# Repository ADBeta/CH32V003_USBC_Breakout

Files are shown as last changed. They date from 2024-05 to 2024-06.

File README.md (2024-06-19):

# CH32V003 USB C Breakout

## Project Description
A Breakout Board for the QFN Variant of the CH32V003, with pins broken out for
I2C, SPI, UART, USB, and with a USB-C Connector, and an NRST Button.  

This Board has been designed with generic and minimal parts, to make the
production and assembly of these boards easy and cheap for novices, looking to
get into the hobby and/or use the `CH32V003` Chips

NOTE: If using the USB Pins for other purposes, please keep in mind that USB_DM
and USB_PU are connected togehter with a 1.5K resistor. Remove this if needed

## Gallery
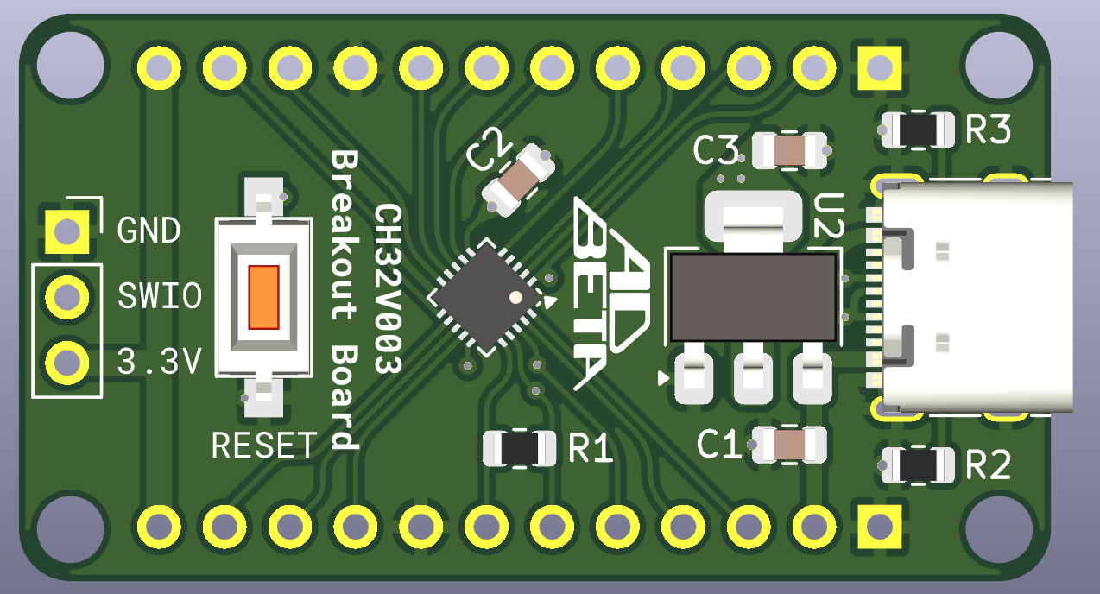
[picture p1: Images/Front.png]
Front of Board

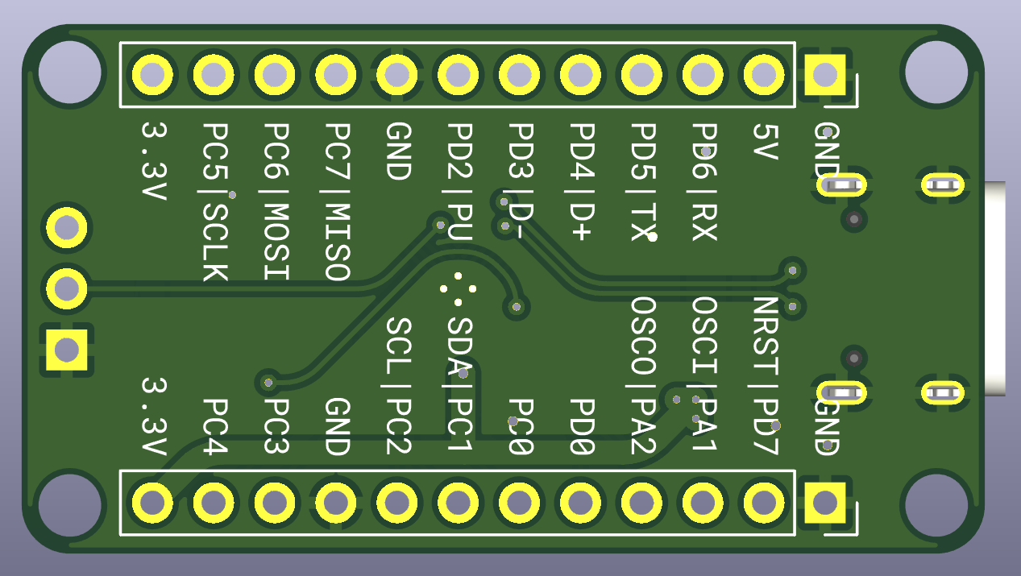
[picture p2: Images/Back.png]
Back of Board

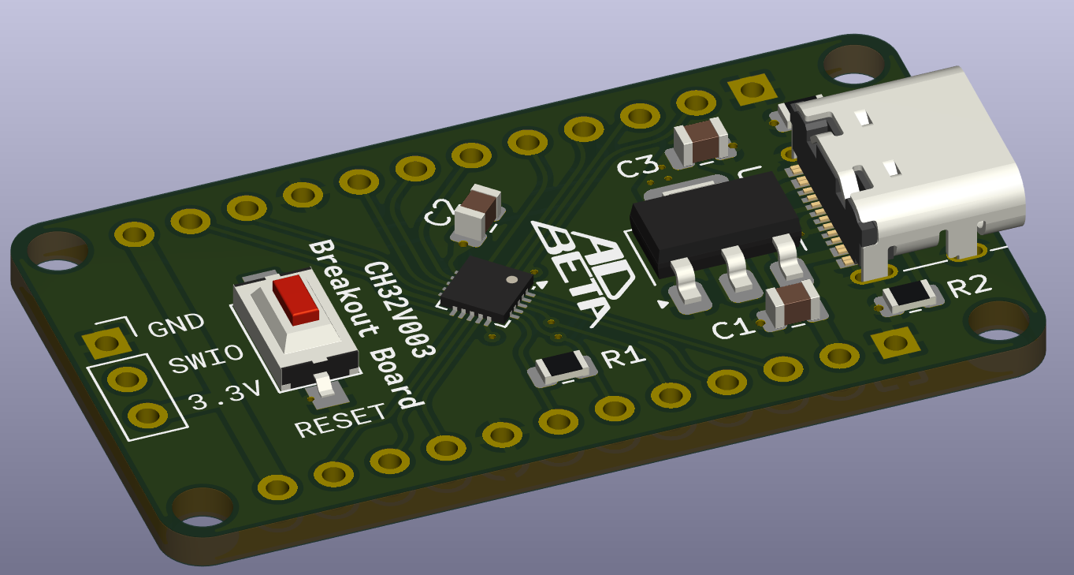
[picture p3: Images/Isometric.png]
Isometric View of Board

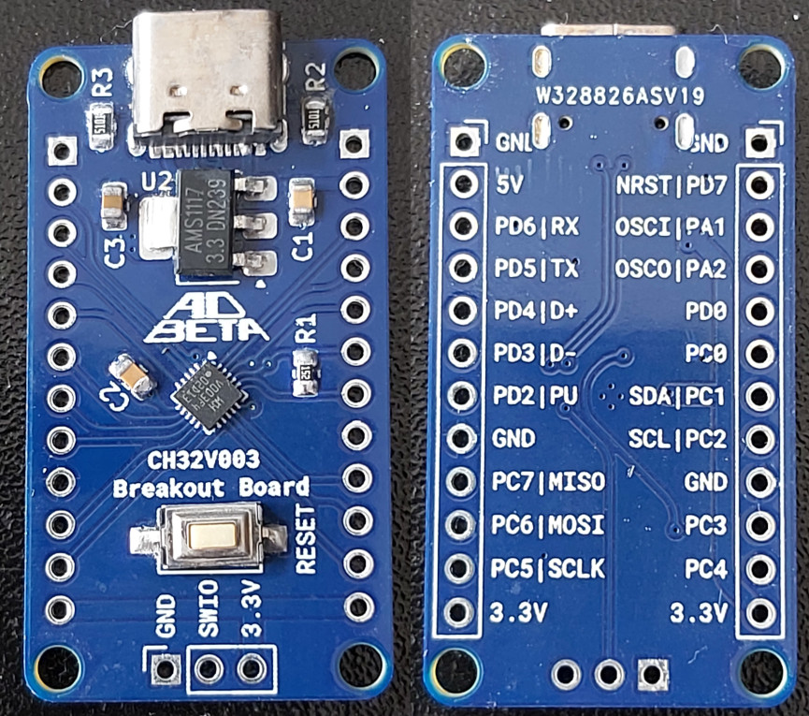
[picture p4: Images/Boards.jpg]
Real Printed Boards


## Parts List
`J2    Generic 16 Pin USB C Connector`  
`J1     3 x 2.54mm (0.1") Pin Header`  
`J3    12 x 2.54mm (0.1") Pin Header`  
`J4    12 x 2.54mm (0.1") Pin Header`  

`R1    0805 1.5K Resistor`  
`R2    0805 5.1K Resistor (Can leave unpopulated, or use 5K - 22K instead)`  
`R3    0805 5.1K Resistor (Can leave unpopulated, or use 5K - 22K instead)`  

`C1    0805 100nF Capacitor`  
`C2    0805 100nF Capacitor`  
`C3    0805 10uF  Capacitor (Can leave unpopulated, or use 100nF instead)`  

`SW1   Generic 6mm x 3mm Tactile Button`  

`U1    QFN20 0.4mm Pitch CH32V003`  
`U2    AMS1117 3.3c Voltage Regulator`  

## Pinout
**USB**
   * `Pullup  PD2`
   * `D-      PD3`
   * `D+      PD4`

**SPI**
   * `SCLK    PC5`
   * `MOSI    PC6`
   * `MISO    PC7`

**I2C**
   * `SDA     PC1`
   * `SCL     PC2`

**UART**
   * `TX      PD5`
   * `RX      PD6`

## Dimensions
The PCB is 22mm x 40mm, with 4 x 2.6mm holes in a rectangle pattern; 18mm x 36mm.  
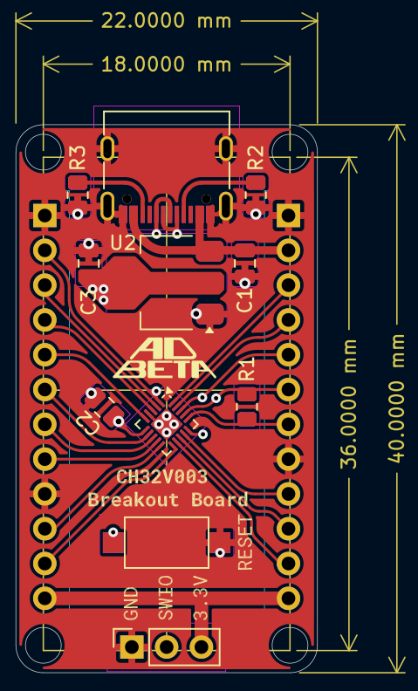
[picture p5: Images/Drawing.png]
Drawing of Board


----
Copyright (c) ADBeta 2024    Last Modified: 29 May 2024

This program is free software; you can redistribute it and/or modify it under
the terms of the GNU General Public License as published by the Free Software
Foundation; either version 2 of the License, 
or (at your option) any later version.

This program is distributed in the hope that it will be useful, but 
WITHOUT ANY WARRANTY; without even the implied warranty of MERCHANTABILITY or
FITNESS FOR A PARTICULAR PURPOSE.  
See the GNU General Public License for more details.

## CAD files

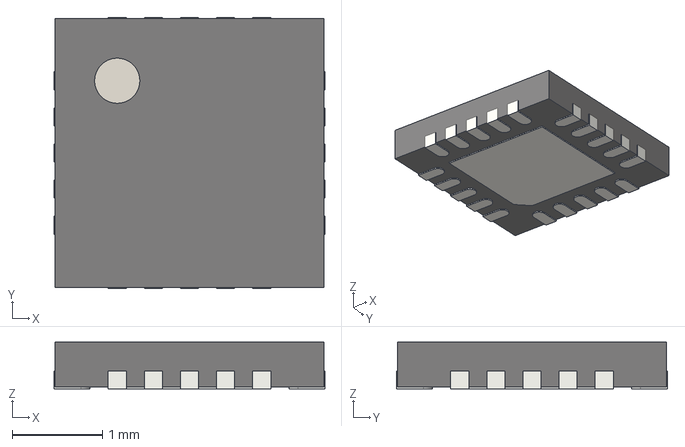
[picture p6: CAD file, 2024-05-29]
attic/UQFN-20-1EP_3x3mm_P0.4mm_EP1.85x1.85mm.step
3.00 x 3.00 x 0.52 mm

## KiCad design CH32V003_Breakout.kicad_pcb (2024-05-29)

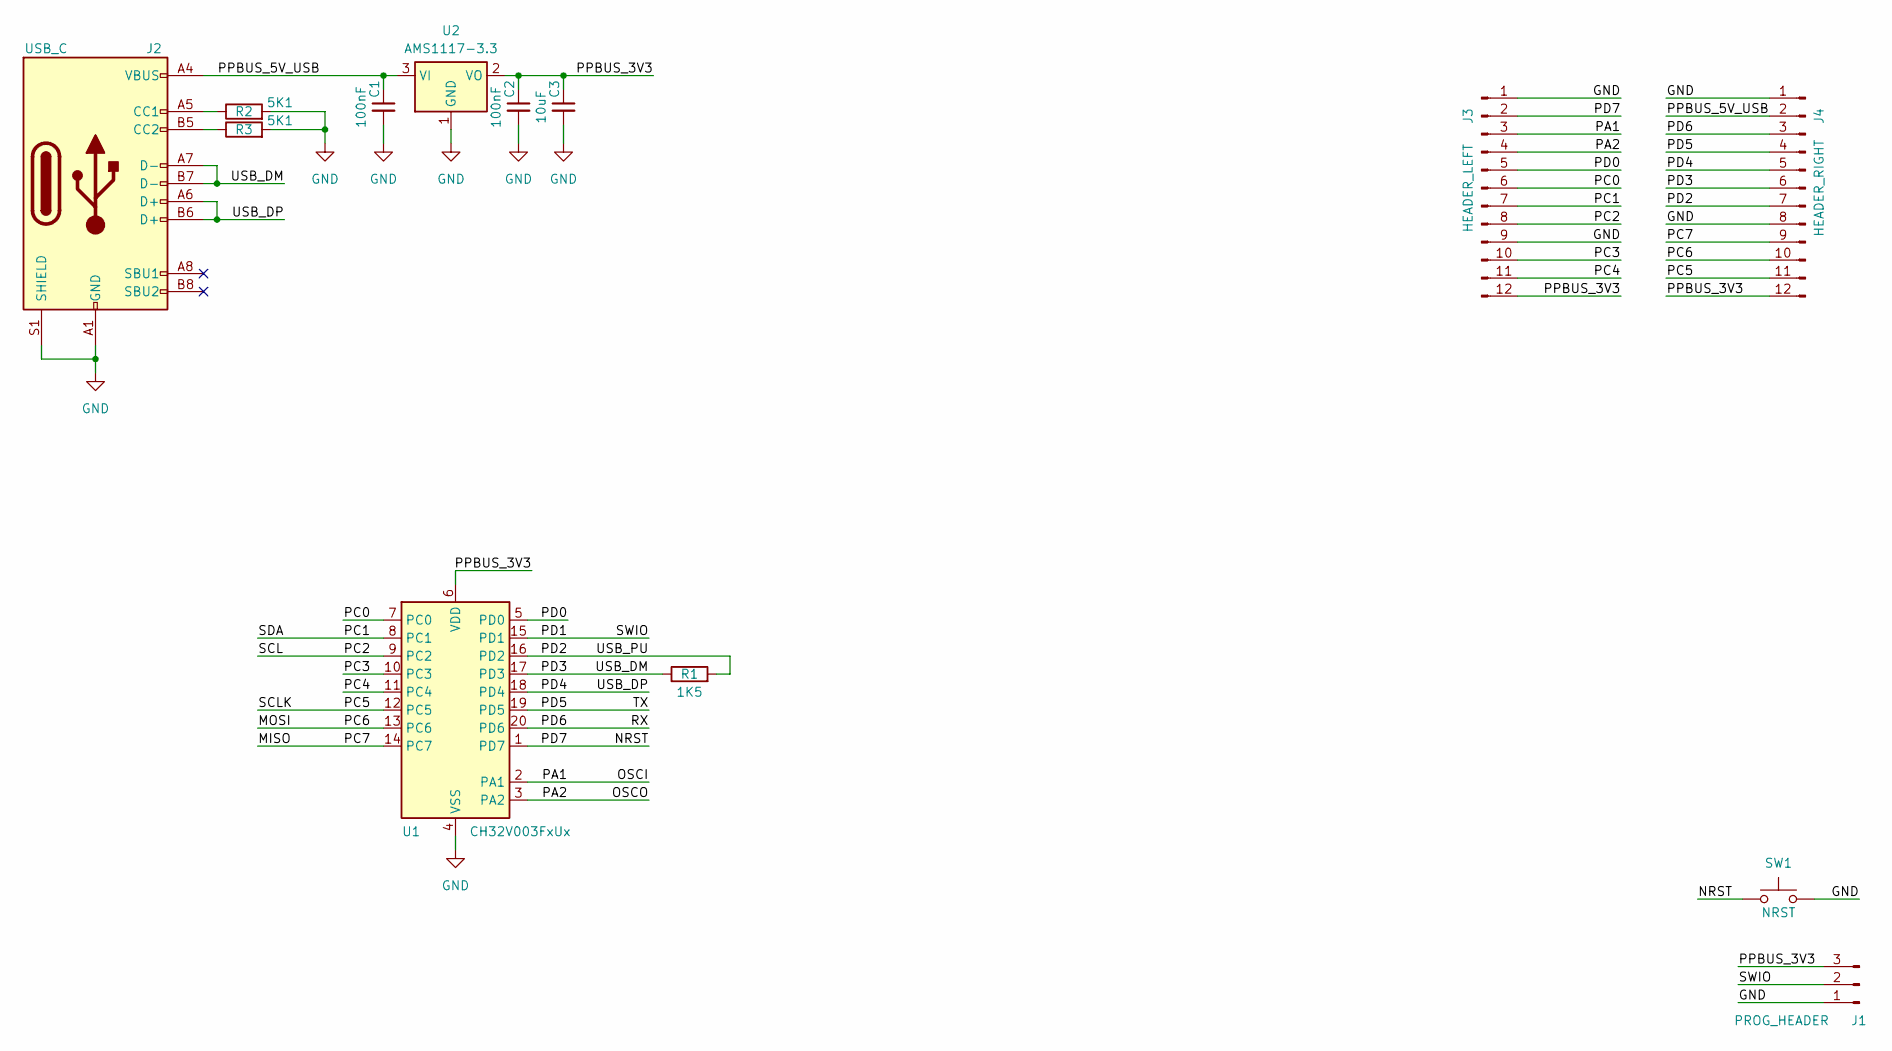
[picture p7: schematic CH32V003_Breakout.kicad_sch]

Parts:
C1, C2: 100nF; C_0805_2012Metric
C3: 10uF; C_0805_2012Metric
J1: PROG_HEADER; PinSocket_1x03_P2.54mm_Vertical
J2: USB_C; USB_C_Receptacle_G-Switch_GT-USB-7010ASV
J3: HEADER_LEFT; PinSocket_1x12_P2.54mm_Vertical
J4: HEADER_RIGHT; PinSocket_1x12_P2.54mm_Vertical
R1: 1K5; R_0805_2012Metric
R2, R3: 5K1; R_0805_2012Metric
SW1: NRST; SW_SPST_CK_RS282G05A3
U1: CH32V003FxUx; QFN-20-1EP_3x3mm_P0.4mm_EP1.65x1.65mm
U2: AMS1117-3.3; SOT-223-3_TabPin2

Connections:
/MISO: J4.9, U1.14 (PC7)
/MOSI: J4.10, U1.13 (PC6)
/NRST: J3.2, SW1.1, U1.1 (PD7)
/OSCI: J3.3, U1.2 (PA1)
/OSCO: J3.4, U1.3 (PA2)
/PC0: J3.6, U1.7 (PC0)
/PC1: J3.7, U1.8 (PC1)
/PC2: J3.8, U1.9 (PC2)
/PC3: J3.10, U1.10 (PC3)
/PC4: J3.11, U1.11 (PC4)
/PC5: J4.11, U1.12 (PC5)
/PD0: J3.5, U1.5 (PD0)
/PD1: J1.2, U1.15 (PD1)
/PD2: J4.7, R1.2, U1.16 (PD2)
/PD3: J2.A7 (D-), J2.B7 (D-), J4.6, R1.1, U1.17 (PD3)
/PD4: J2.A6 (D+), J2.B6 (D+), J4.5, U1.18 (PD4)
/PD5: J4.4, U1.19 (PD5)
/PD6: J4.3, U1.20 (PD6)
/PPBUS_3V3: C2.1, C3.1, J1.3, J3.12, J4.12, U1.6 (VDD), U2.2 (VO)
/PPBUS_5V_USB: C1.1, J2.A4 (VBUS), J2.A9 (VBUS), J2.B4 (VBUS), J2.B9 (VBUS), J4.2, U2.3 (VI)
GND: C1.2, C2.2, C3.2, J1.1, J2.A1 (GND), J2.A12 (GND), J2.B1 (GND), J2.B12 (GND), J2.S1 (SHIELD), J3.1, J3.9, J4.1, J4.8, R2.2, R3.2, SW1.2, U1.4 (VSS), U1.21 (VSS), U2.1 (GND)
unnamed: J2.A5 (CC1), R2.1
unnamed: J2.B5 (CC2), R3.1

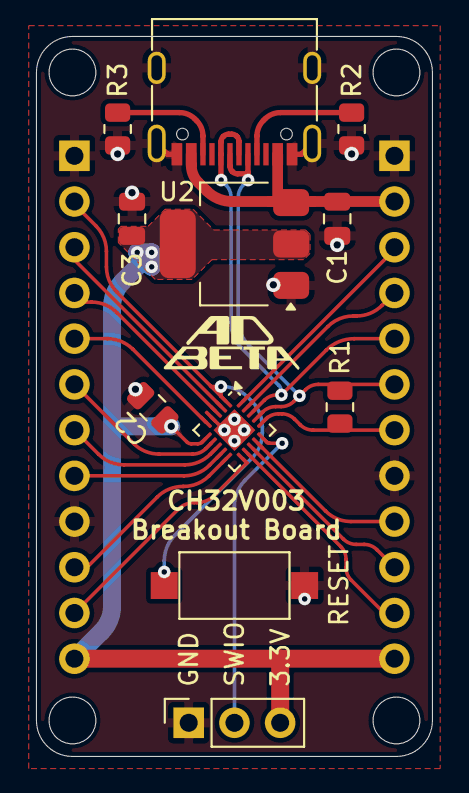
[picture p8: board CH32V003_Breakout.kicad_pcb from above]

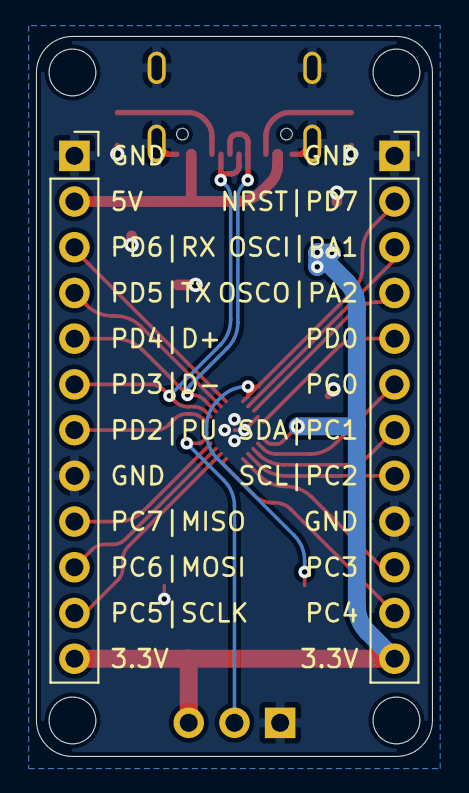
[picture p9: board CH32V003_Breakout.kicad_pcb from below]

Board: 2 copper layers, 22.0 x 40.0 mm, 13 parts (2 on the bottom side), 23 nets.

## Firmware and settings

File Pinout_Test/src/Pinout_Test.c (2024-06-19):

/******************************************************************************
* A very simple program to test all of the Pins on the breakout board to 
* ensure all pins are soldered correctly.
*
* Attach 1K resitors and LEDs to each of the pins listed in the program.
*
* ADBeta (c)   2024
******************************************************************************/
#include "lib_GPIOCTRL.h"
#include "ch32v003fun.h"
#include <stdio.h>

const gpio_pin_t port_a[] = {GPIO_PA1, GPIO_PA2};
const gpio_pin_t port_c[] = {GPIO_PC0, GPIO_PC1, GPIO_PC2, GPIO_PC3, GPIO_PC4, GPIO_PC5, GPIO_PC6, GPIO_PC7};
// PD1 is SWIO and PD7 is NRST
const gpio_pin_t port_d[] = {GPIO_PD0, GPIO_PD2, GPIO_PD3, GPIO_PD4, GPIO_PD5, GPIO_PD6};


int main()
{
	SystemInit();



	// Setup all the applicable pins
	for(uint8_t pai = 0; pai < 2; pai++) gpio_digital_write(port_a[pai], GPIO_HIGH);
	for(uint8_t pci = 0; pci < 8; pci++) gpio_digital_write(port_c[pci], GPIO_HIGH);
	for(uint8_t pdi = 0; pdi < 6; pdi++) gpio_digital_write(port_d[pdi], GPIO_HIGH);


	while(1)
	{
		/* PORT A */
		for(uint8_t pai = 0; pai < 2; pai++)
		{
			gpio_digital_write(port_a[pai], GPIO_HIGH);
			gpio_set_mode(port_a[pai], OUTPUT_10MHZ_PP);
			Delay_Ms(250);
			gpio_set_mode(port_a[pai], INPUT_FLOATING);
		}


		/* PORT C */
		for(uint8_t pci = 0; pci < 8; pci++)
		{
			gpio_digital_write(port_c[pci], GPIO_HIGH);
			gpio_set_mode(port_c[pci], OUTPUT_10MHZ_PP);
			Delay_Ms(250);
			gpio_set_mode(port_c[pci], INPUT_FLOATING);
		}


		/* PORT D */
		for(uint8_t pdi = 0; pdi < 6; pdi++)
		{
			gpio_digital_write(port_d[pdi], GPIO_HIGH);
			gpio_set_mode(port_d[pdi], OUTPUT_10MHZ_PP);
			Delay_Ms(250);
			gpio_set_mode(port_d[pdi], INPUT_FLOATING);
		}
	}
}

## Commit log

2024-05-28 Started PCB Layout
    [CH32V003_Breakout.kicad_pcb]
2024-05-29 V1.0 Board Release
    [CH32V003_Breakout.kicad_pcb, CH32V003_Breakout.kicad_sch, UQFN-20-1EP_3x3mm_P0.4mm_EP1.85x1.85mm.step]

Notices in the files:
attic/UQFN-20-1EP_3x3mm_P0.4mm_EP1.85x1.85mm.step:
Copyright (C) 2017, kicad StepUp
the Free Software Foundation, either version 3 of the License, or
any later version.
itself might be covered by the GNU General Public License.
